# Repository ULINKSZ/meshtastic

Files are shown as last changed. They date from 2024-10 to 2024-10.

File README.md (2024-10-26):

# Meshtastic Product Development
Meshtastic devices can help explorers stay connected, share locations, send emergency distress signals, etc. in remote mountainous areas without mobile phone signals during outdoor activities such as hiking and mountaineering. In some small communities or remote villages, Meshtastic mesh networks can be built to meet local communication needs, such as community notifications and emergency warnings. In the event that natural disasters (such as earthquakes and floods) damage traditional communication infrastructure, Meshtastic devices can be quickly deployed to establish emergency communication networks to provide communication means for rescue workers and disaster victims.
=======
## Open source code link (https://github.com/meshtastic/meshtastic)
## The following are all the contents in this warehouse organized into separate directories. Each directory stores the corresponding information. When you need it, go to the specified directory to search. The name of each directory is shown below:
### Docs is the product hardware specification and hardware parameters
### Firmware is used to store the hex and bin files burned into the hardware
### Hardware/meshtastiv_V1.0 is the product schematic and PCB board. Please use Kicad software to open and view it. Kicad download address (https://www.kicad.org/)
### Instructions are product burning and usage methods and how to quickly locate. Please open the folder and click Meshtastic devices or How to quickly locate files to view them.
### Software/firmware-master is the product source code. Please download VSCode to open and view it. VsCode download address (https://code.visualstudio.com/)

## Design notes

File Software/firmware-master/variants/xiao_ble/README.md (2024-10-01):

#

<p align="center" style="font-size: 28px;">
    Xiao BLE/BLE Sense + Ebyte E22-900M30S
</p>

<p align="center" style="font-size: 20px;">
    A step-by-step guide for macOS and Linux
</p>

## Introduction

This guide will walk you through everything needed to get the Xiao BLE (or BLE Sense) running Meshtastic using an Ebyte E22-900M30S LoRa module. The combination of the E22 with an nRF52840 MCU is desirable because it allows for both very low idle (Rx) power draw <i>and</i> high transmit power. The Xiao BLE is a small but surprisingly well-appointed nRF52840 board, with enough GPIO for most Meshtastic applications and a built-in LiPo charger. The E22, on the other hand, is a famously inscrutable and mysterious beast. It is one of the more readily available LoRa modules capable of transmitting at 30 dBm, and includes an LNA to boost its Rx sensitivity a few dB beyond that of the SX1262. However, its documentation is relatively sparse overall, and seems to merely hint at (or completely omit) several key details regarding its functionality. Thus, much of what follows is a synthesis of my observations and inferences over the course of many hours of trial and error.

<h3>Acknowledgement and friendly disclaimer</h3>

Huge thanks to those in the community who have forged the way with the E22, without whose hard work none of this would have been possible! (thebentern, riddick, rainer_vie, beegee-tokyo, geeksville, caveman99, Der_Bear, PlumRugOfDoom, BigCorvus, and many others.)

<br>

Please take the conclusions here as a tentative work in progress, representing my current (and fairly limited) understanding of the E22 when paired with this particular MCU. It is my hope that this guide will be helpful to others who are interested in trying a DIY Meshtastic build, and also be subject to revision by folks with more experience and better test equipment.

### Obligatory liability disclaimer

This guide and all associated content is for informational purposes only. The information presented is intended for consumption only by persons having appropriate technical skill and judgement, to be used entirely at their own discretion and risk. The authors of this guide in no way provide any warranty, express or implied, toward the content herein, nor its correctness, safety, or suitability to any particular purpose. By following the instructions in this guide in part or in full, you assume all responsibility for all potential risks, including but not limited to fire, property damage, bodily injury, and death.

### Note

These instructions assume you are running macOS or Linux, but it should be relatively easy to translate each command for Windows. (In this case, in step 2 below, each line of `xiao_ble.sh` would also need to be converted to the equivalent Windows CLI command and run individually.)

## 1. Update Bootloader

The first thing you will need to do is update the Xiao BLE's bootloader. The stock bootloader is functionally very similar to the Adafruit nRF52 UF2 bootloader, but apparently not quite enough so to work with Meshtastic out of the box.

1. Connect the Xiao BLE to your computer via USB-C.

2. Install `adafruit-nrfutil` by following the instructions <a href="https://github.com/adafruit/Adafruit_nRF52_nrfutil">here</a>.

3. Open a terminal window and navigate to `firmware/variants/xiao_ble` (where `firmware` is the directory into which you have cloned the <a href="https://github.com/meshtastic/firmware">Meshtastic firmware repo</a>).

4. Run the following command, replacing `/dev/cu.usbmodem2101` with the serial port your Xiao BLE is connected to:

   ```bash
   adafruit-nrfutil --verbose dfu serial --package xiao_nrf52840_ble_bootloader-0.7.0-22-g277a0c8_s140_7.3.0.zip --port /dev/cu.usbmodem2101 -b 115200 --singlebank --touch 1200
   ```

5. If all goes well, the Xiao BLE's red LED should start to pulse slowly, and you should see a new USB storage device called `XIAO-BOOT` appear under `Locations` in Finder.

&nbsp;

## 2. PlatformIO Environment Preparation

Before building Meshtastic for the Xiao BLE + E22, it is necessary to pull in SoftDevice 7.3.0 and its associated linker script (nrf52840_s140_v7.ld) from Seeed Studio's Arduino core. The `xiao_ble.sh` script does this.

1. In your terminal window, run the following command:

   ```bash
   sudo ./xiao_ble.sh
   ```

&nbsp;

## 3. Build Meshtastic

At this point, you should be able to build the firmware successfully.

1. In VS Code, press `Command Shift P` to bring up the command palette.

2. Search for and run the `Developer: Reload Window` command.

3. Bring up the command palette again with `Command Shift P`. Search for and run the `PlatformIO: Pick Project Environment` command.

4. In the list of environments, select `env:xiao_ble`. PlatformIO may update itself for a minute or two, and should let you know once done.

5. Return to the command palette once again (`Command Shift P`). Search for and run the `PlatformIO: Build` command.

6. PlatformIO will build the project. After a few minutes you should see a green `SUCCESS` message.

&nbsp;

## 4. Wire the board

Connecting the E22 to the Xiao BLE is straightforward, but there are a few gotchas to be mindful of.

- <strong>On the Xiao BLE:</strong>

  - Pins D4 and D5 are currently mapped to `PIN_WIRE_SDA` and `PIN_WIRE_SCL`, respectively. If you are not using I²C and would like to free up pins D4 and D5 for use as GPIO, `PIN_WIRE_SDA` and `PIN_WIRE_SCL` can be reassigned to any two other unused pin numbers.

  - Pins D6 and D7 were originally mapped to the TX and RX pins for serial interface 1 (`PIN_SERIAL1_RX` and `PIN_SERIAL1_TX`) but are currently set to -1 in `variant.h`. If you need to expose a serial interface, you can restore these pins and move e.g. `SX126X_RXEN` to pin 4 or 5 (the opposite should work too).

- <strong>On the E22:</strong>

  - There are two options for the E22's `TXEN` pin:

    1. It can be connected to the MCU on the pin defined as `SX126X_TXEN` in `variant.h`. In this configuration, the MCU will control Tx/Rx switching "manually". As long as `SX126X_TXEN` and `SX126X_RXEN` are both defined in `variant.h` (and neither is set to `RADIOLIB_NC`), `SX126xInterface.cpp` will initialize the E22 correctly for this mode.

    2. Alternately, it can be connected to the E22's `DIO2` pin only, with neither `TXEN` nor `DIO2` being connected to the MCU. In this configuration, the E22 will control Tx/Rx switching automatically. In `variant.h`, as long as `SX126X_TXEN` is defined as `RADIOLIB_NC`, and `SX126X_RXEN` is defined and connected to the E22's `RXEN` pin, and `E22_TXEN_CONNECTED_TO_DIO2` is defined, `SX126xInterface.cpp` will initialize the E22 correctly for this mode. This configuration frees up a GPIO, and presents no drawbacks that I have found.

    - Note that any combination other than the two described above will likely result in unexpected behavior. In my testing, some of these other configurations appeared to "work" at first glance, but every one I tried had at least one of the following flaws: weak Tx power, extremely poor Rx sensitivity, or the E22 overheating because TXEN was never pulled low, causing its PA to stay on indefinitely.

    - Along the same lines, it is a good idea to check the E22's temperature frequently by lightly touching the shield. If you feel the shield getting hot (i.e. approaching uncomfortable to touch) near pins 1, 2, and 3, something is probably misconfigured; disconnect both the Xiao BLE and E22 from power and double check wiring and pin mapping.

  - Whether you opt to let the E22 control Rx and Tx or handle this manually, <strong>the E22's `RXEN` pin must always be connected to the MCU</strong> on the pin defined as `SX126X_RXEN` in `variant.h`.

<h3>Note</h3>

The default pin mapping in `variant.h` uses 'automatic Tx/Rx switching' mode. If you wire your board for manual Rx/Tx switching, make sure to update `variant.h` accordingly by commenting/uncommenting the necessary lines in the 'E22 Tx/Rx control options' section.

&nbsp;

---

&nbsp;

<h3>Example wiring for "E22 automatic Tx/Rx switching" mode:</h3>
&nbsp;

<strong>MCU -> E22 connections</strong>
| Xiao BLE pin | variant.h definition | E22 pin | Notes |
| :--- | :--- | :---| :--- |
| D0 | SX126X_CS | 19 (NSS) | |
| D1 | SX126X_DIO1 | 13 (DIO1) | |
| D2 | SX126X_BUSY | 14 (BUSY) | |
| D3 | SX126X_RESET | 15 (NRST) | |
| D7 | SX126X_RXEN | 6 (RXEN) | These pins must still be connected, and `SX126X_RXEN` defined in `variant.h`, otherwise Rx sensitivity will be poor. |
| D8 | PIN_SPI_SCK | 18 (SCK) | |
| D9 | PIN_SPI_MISO | 16 (MISO) | |
| D10 | PIN_SPI_MOSI | 17 (MOSI) | |

&nbsp;
&nbsp;

<strong>E22 -> E22 connections:</strong>
| E22 pin | E22 pin | Notes |
| :--- | :--- | :--- |
| TXEN | DIO2 | These must be physically connected for automatic Tx/Rx switching to work. |

<h3>Note</h3>

The schematic (`xiao-ble-e22-schematic.png`) in the `eagle-project` directory uses this wiring.

&nbsp;

---

&nbsp;

<h3>Example wiring for "Manual Tx/Rx switching" mode:</h3>

<strong>MCU -> E22 connections</strong>
| Xiao BLE pin | variant.h definition | E22 pin | Notes |
| :--- | :--- | :---| :--- |
| D0 | SX126X_CS | 19 (NSS) | |
| D1 | SX126X_DIO1 | 13 (DIO1) | |
| D2 | SX126X_BUSY | 14 (BUSY) | |
| D3 | SX126X_RESET | 15 (NRST) | |
| D6 | SX126X_TXEN | 7 (TXEN) | |
| D7 | SX126X_RXEN | 6 (RXEN) | |
| D8 | PIN_SPI_SCK | 18 (SCK) | |
| D9 | PIN_SPI_MISO | 16 (MISO) | |
| D10 | PIN_SPI_MOSI | 17 (MOSI) | |

<strong>E22 -> E22 connections:</strong> (none)

&nbsp;

## 5. Flash the firmware to the Xiao BLE

1. Double press the Xiao's `reset` button to put it in bootloader mode.
2. In a terminal window, navigate to the Meshtastic firmware repo's root directory, and from there to `.pio/build/xiao_ble`.
3. Convert the generated `.hex` file into a `.uf2` file:

   ```bash
   ../../../bin/uf2conv.py firmware.hex -c -o firmware.uf2 -f 0xADA52840
   ```

4. Copy the new `.uf2` file to the Xiao's mass storage volume:

   ```bash
   cp firmware.uf2 /Volumes/XIAO-BOOT
   ```

5. The Xiao's red LED will flash for several seconds as the firmware is copied.
6. Once the firmware is copied, to verify it is running, run the following command:

   ```bash
   meshtastic --noproto
   ```

7. Then, press the Xiao's `reset` button again. You should see a lot of debug output logged in the terminal window.

&nbsp;

## 6. Troubleshooting

- If after flashing Meshtastic, the Xiao is bootlooped, look at the serial output (you can see this by running `meshtastic --noproto` with the device connected to your computer via USB).

  - If you see that the SX1262 init result was -2, this likely indicates a wiring problem; double check your wiring and pin mapping in `variant.h`.

  - If you see an error mentioning tinyFS, this may mean you need to reformat the Xiao's storage:

    1. Double press the `reset` button to put the Xiao in bootloader mode.

    2. In a terminal window, navigate to the Meshtastic firmware repo's root directory, and from there to `variants/xiao_ble`.

    3. Run the following command: &nbsp;`cp xiao-ble-internal-format.uf2 /Volumes/XIAO-BOOT`

    4. The Xiao's red LED will flash briefly as the filesystem format firmware is copied.

    5. Run the following command: &nbsp;`meshtastic --noproto`

    6. In the output of the above command, you should see a message saying "Formatting...done".

    7. To flash Meshtastic again, repeat the steps in section 5 above.

  - If you don't see any specific error message, but the boot process is stuck or not proceeding as expected, this might also mean there is a conflict in `variant.h`. If you have made any changes to the pin mapping, ensure they do not result in a conflict. If all else fails, try reverting your changes and using the known-good configuration included here.

  - The above might also mean something is wired incorrectly. Try reverting to one of the known-good example wirings in section 4.

- If the E22 gets hot to the touch:
  - The power amplifier is likely running continually. Disconnect it and the Xiao from power immediately, and double check wiring and pin mapping. In my experimentation this occurred in cases where TXEN was inadvertenly high (usually due to a pin mapping conflict).

&nbsp;

## 7. Notes

- There are several anecdotal recommendations regarding the Tx power the E22's internal SX1262 should be set to in order to achieve the advertised output of 30 dBm, ranging from 4 (per <a href="https://github.com/jgromes/RadioLib/wiki/High-power-Radio-Modules-Guide">this article</a> in the RadioLib github repo) to 22 (per <a href="https://discord.com/channels/867578229534359593/871539930852130866/976472577545490482">this conversation</a> from the Meshtastic Discord). When paired with the Xiao BLE in the configurations described above, I observed that the output is at its maximum when Tx power is set to 22.

- To achieve its full output, the E22 should have a bypass capacitor from its 5V supply to ground. 100 µF works well.

- The E22 will happily run on voltages lower than 5V, but the full output power will not be realized. For example, with a fully charged LiPo at 4.2V, Tx power appears to max out around 26-27 dBm.

&nbsp;

## 8. Testing Methodology

During what became a fairly long trial-and-error process, I did a lot of careful testing of Tx power and Rx sensitivity. My methodology in these tests was as follows:

- All tests were conducted between two nodes:

  1. The Xiao BLE + E22 coupled with an <a href="https://www.digikey.com/en/products/detail/abracon-llc/ARRKP4065-S915A/8593263">Abracon ARRKP4065-S915A</a> ceramic patch antenna

  2. A RAK 5005/4631 coupled with a <a href="https://www.streakwave.com/laird-technologies-ma9-5n-55dbi-900mhz-mobile-omni-select-mount">Laird MA9-5N</a> antenna via a 4" U.FL to Type N pigtail.

  - No other nodes were powered up onsite or nearby.

    <br>

- Each node and its antenna was kept in exactly the same position and orientation throughout testing.

- Other environmental factors (e.g. the location and resting position of my body in the room while testing) were controlled as carefully as possible.

- Each test comprised at least five (and often ten) runs, after which the results were averaged.

- All testing was done by sending single-character messages between nodes and observing the received RSSI reported in the message acknowledgement. Messages were sent one by one, waiting for each to be acknowledged or time out before sending the next.

- The E22's Tx power was observed by sending messages from the RAK to the Xiao BLE + E22 and recording the received RSSI.

- The opposite was done to observe the E22's Rx sensitivity: messages were sent from the Xiao BLE + E22 to the RAK, and the received RSSI was recorded.

While this cannot match the level of accuracy achievable with actual test equipment in a lab setting, it was nonetheless sufficient to demonstrate the (sometimes very large) differences in Tx power and Rx sensitivity between various configurations.

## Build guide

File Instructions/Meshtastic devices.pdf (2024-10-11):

# Meshtastic devices

# Project Overview

1. Meshtastic devices can help explorers stay connected in remote

mountainous areas where there is no mobile phone signal, share location, send

emergency distress signals, etc. 2. In some small communities or remote villages, Meshtastic mesh networks

can be built to meet local communication needs, such as notification and

emergency warning in the community. 3. In the event of damage to traditional communication infrastructure caused

by natural disasters (such as earthquakes, floods, etc.), Meshtastic equipment

can be quickly deployed to establish an emergency communication network to

provide a means of communication for rescuers and affected people. Equipment specifications

1. Hardware specifications
1. Hardware device type: wireless communication equipment, GPS positioning

sensor

2. Dimensions and weight: length 4.8cm, width 1.3cm, height 0.9cm
3. Power requirements: 180mAh battery
4. Processor and memory: 32-bit ARM Cortex-M4F processor, 256KB RAM

(random access memory) and 1MB Flash (flash memory). 5. Communication interface: LoRa wireless communication

6. Sensor characteristics: diversified data collection, perception of location

information, low power operation, high sensitivity and accuracy, good

compatibility. 7. Actuator characteristics: remote control capability, fast response, reliability

# and stability. User Interface Specifications (Applications)

1. Interface layout
1. Function menu: for adding devices to connect devices
2. Contact management: Each contact displays information such as name, node

address, etc., which is convenient for users to quickly select contacts to send

messages

3. Map view: The Mesh app interface provides a map view option, which can

display the geographical location of each node on the map

2. Interactive functions
1. Text messages: Users can send and receive text messages to facilitate

simple text communication, such as communicating routes, plans and other

information between teammates during outdoor adventures. 2. Custom message format: Users can define the message format according

to their own needs, which enhances the flexibility and applicability of the

function and meets the special requirements for message content and format

in different scenarios.

3. The device is integrated with a GPS module, which can transmit the

location information of the device in real time. This is useful for outdoor

activities, emergency rescue, and other scenarios, where team members can

quickly understand each other's location for gathering, rescue, or collaborative

# action. Use the specification configuration to burn in

1. Download Visual Studio Code and download Platformio as an extension
2. Download the meshtastic-master archive in GitHub and decompress it

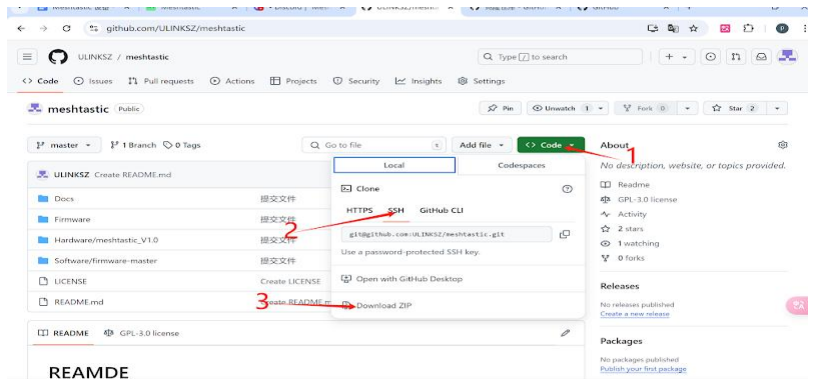
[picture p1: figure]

https://github.com/ULINKSZ/meshtastic

3. Open the firmware-master folder with Visual Studio Code
4. Open

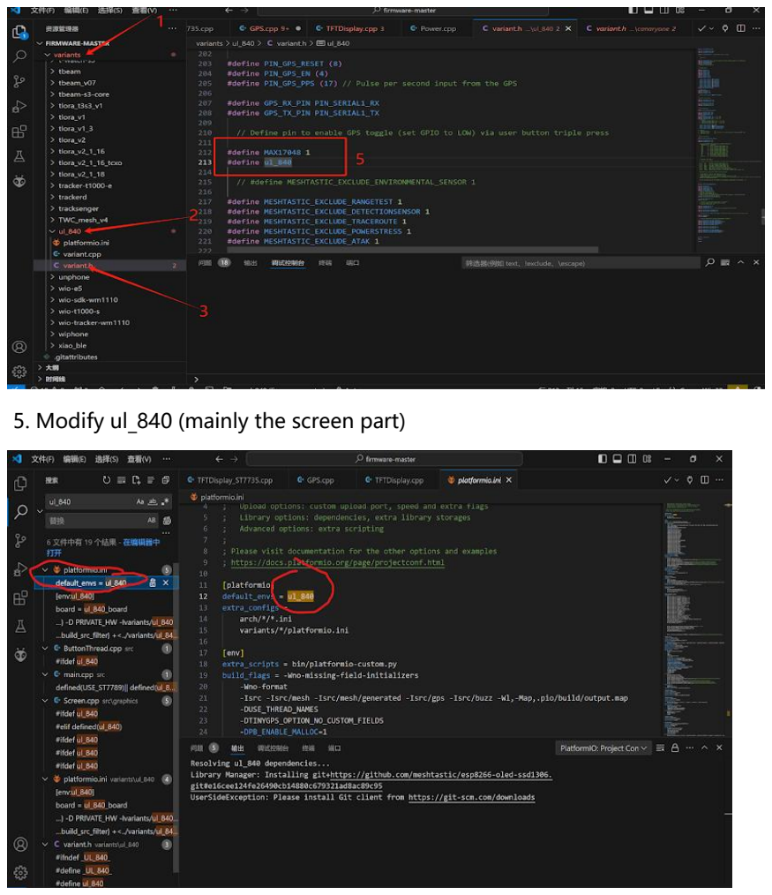
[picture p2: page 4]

5. Modify ul_840 (mainly the screen part)

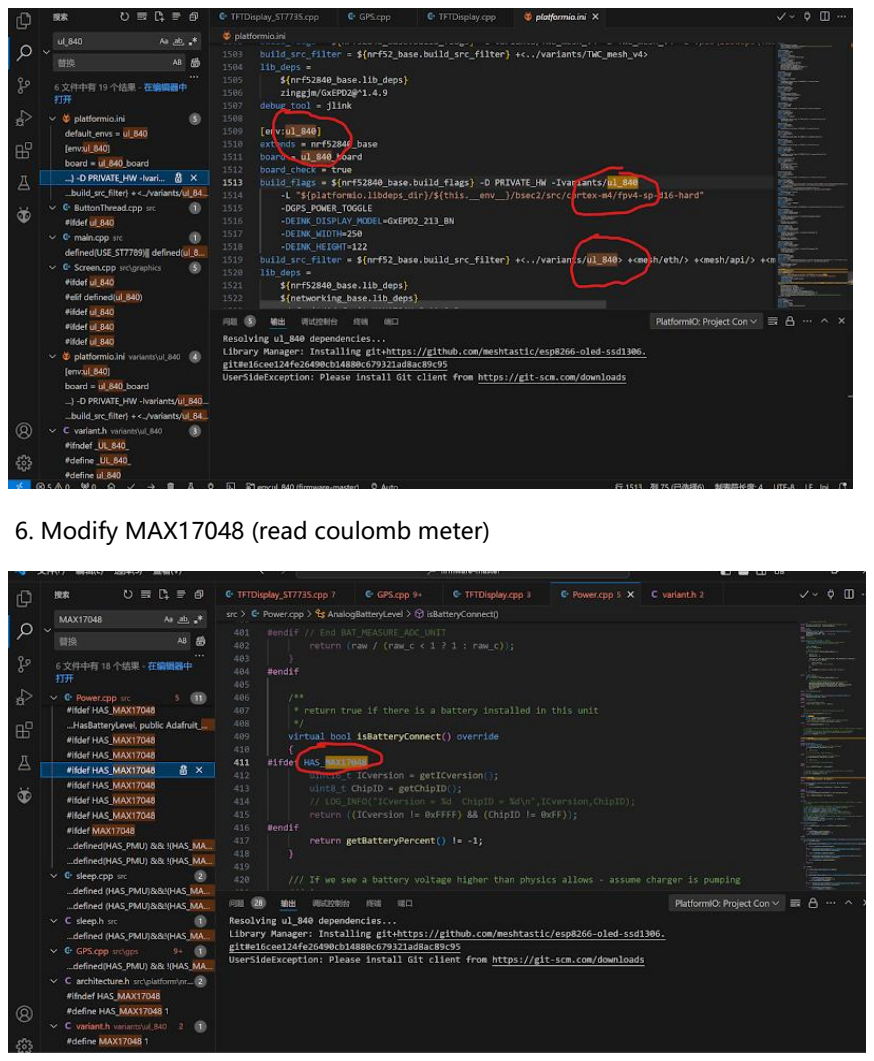
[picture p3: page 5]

6. Modify MAX17048 (read coulomb meter)

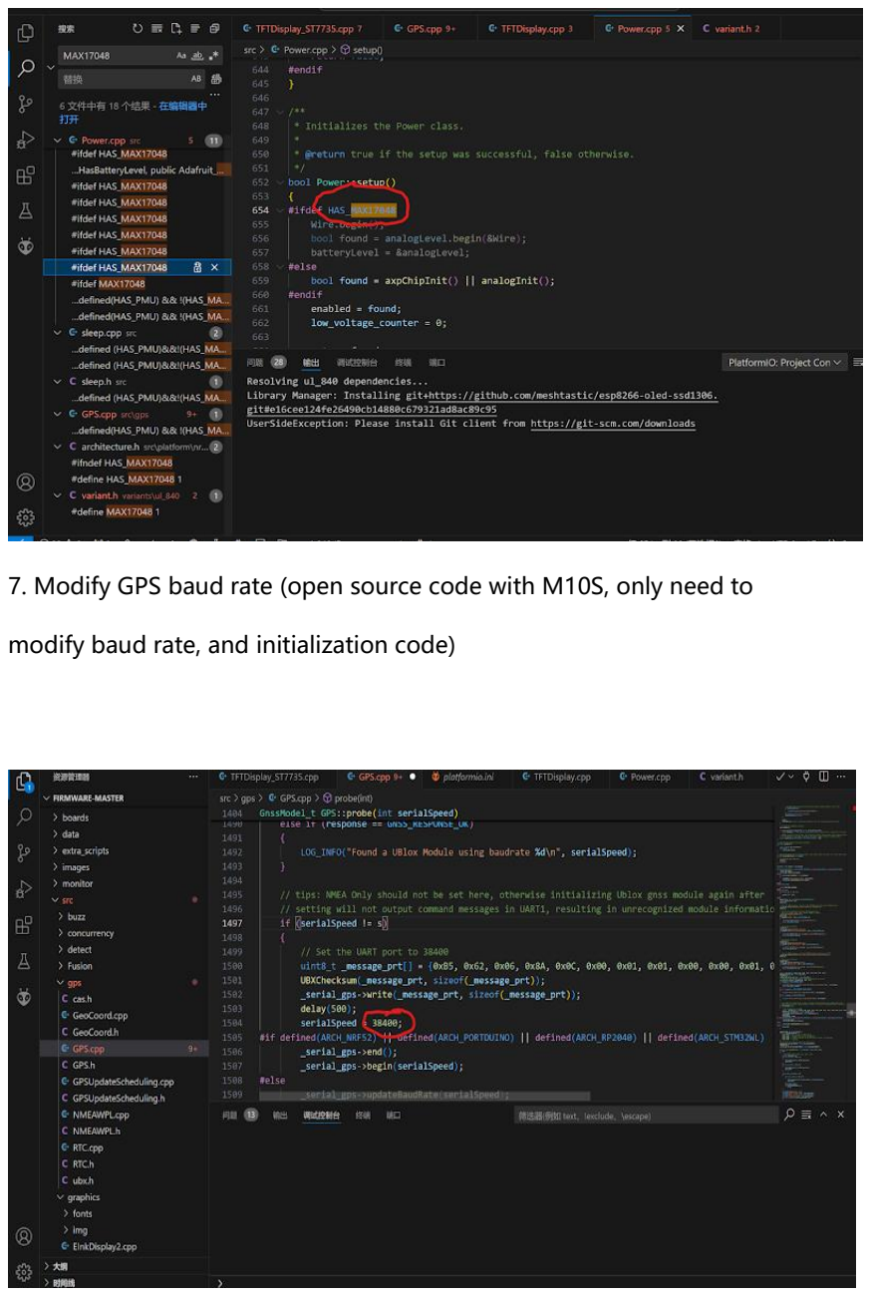
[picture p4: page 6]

7. Modify GPS baud rate (open source code with M10S, only need to

modify baud rate, and initialization code)

8. Configure the serial port

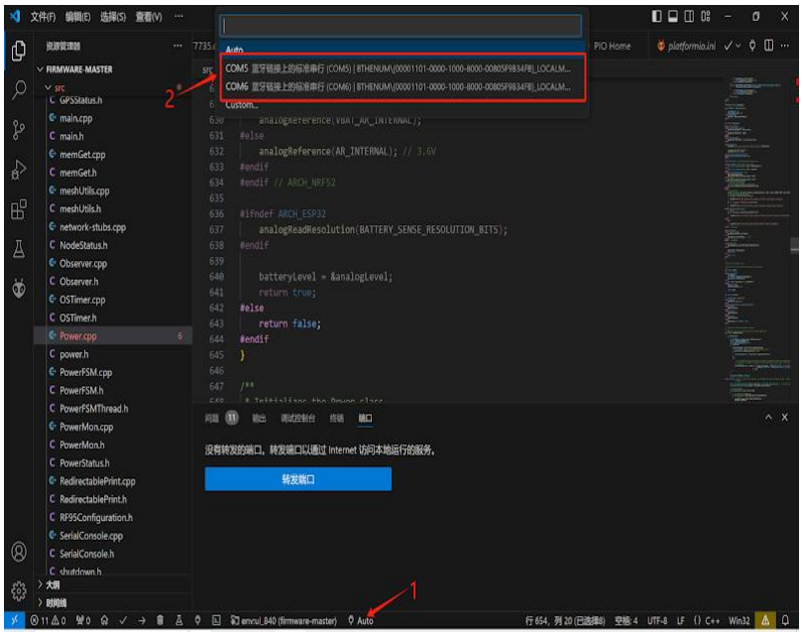
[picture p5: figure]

9. Click √ to compile 1 compilation successfully, compile correctly, click

the arrow to burn in 2 burn successfully.

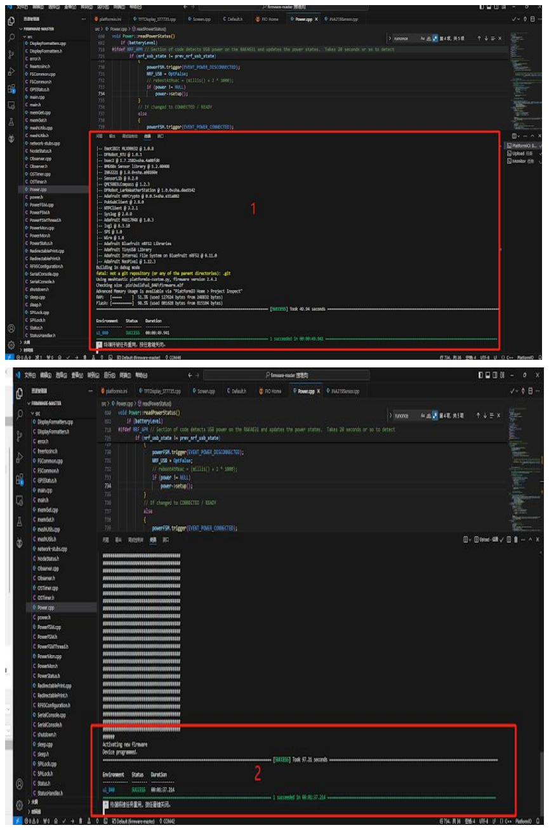
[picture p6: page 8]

# button to use

1. Power off to the left and power on to the right

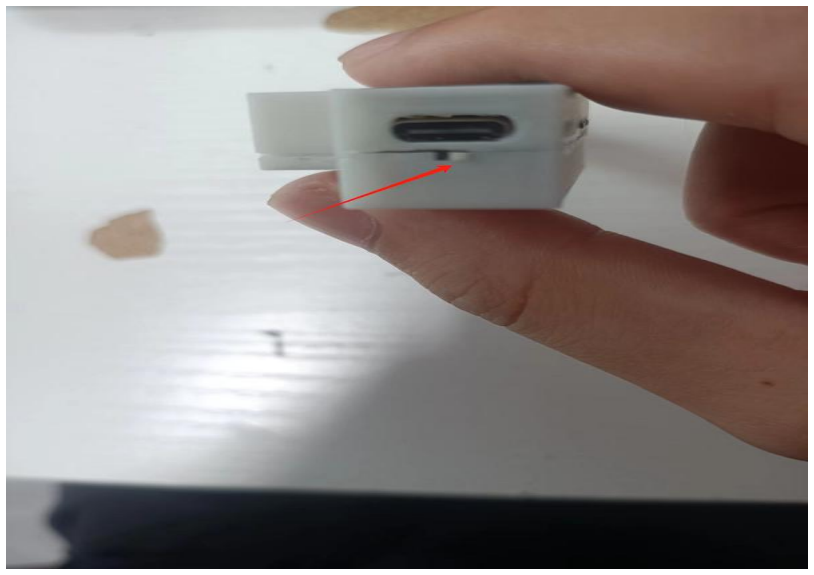
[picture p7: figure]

2. Stand-alone 1 switches the upper and lower navigation bars, stand-alone 2

enters the navigation bar, and stand-alone 3 restarts

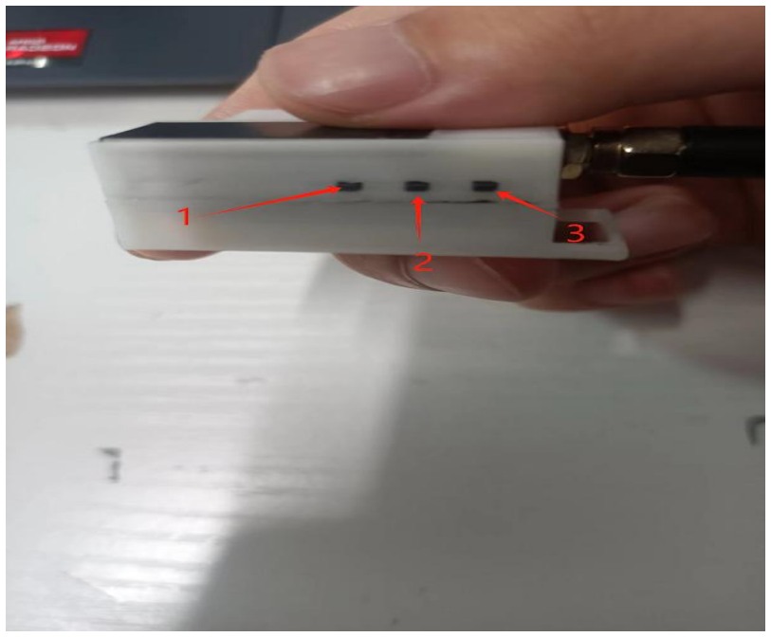
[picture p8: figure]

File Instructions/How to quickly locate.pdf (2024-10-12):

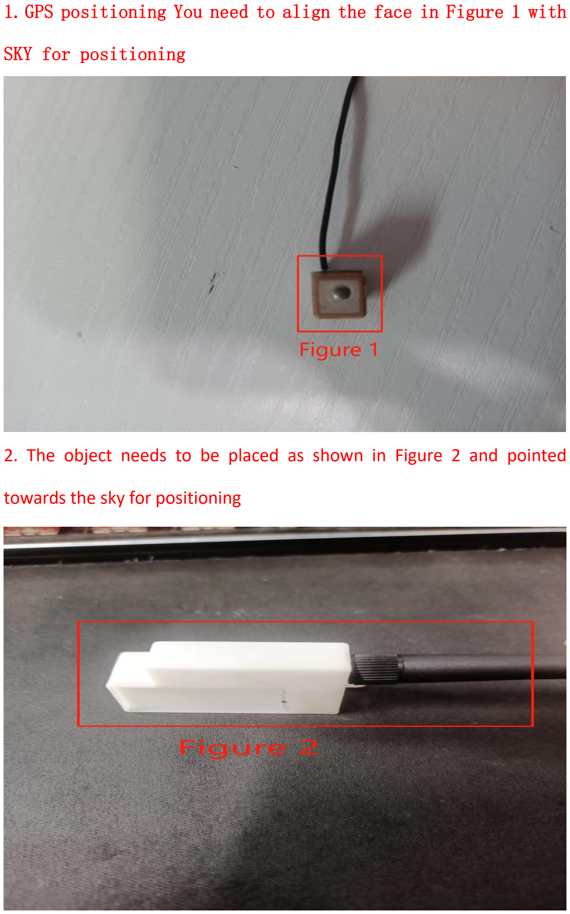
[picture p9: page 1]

1.GPS positioning You need to align the face in Figure 1 with

SKY for positioning

2. The object needs to be placed as shown in Figure 2 and pointed towards the sky for positioning

3.GPS storage location

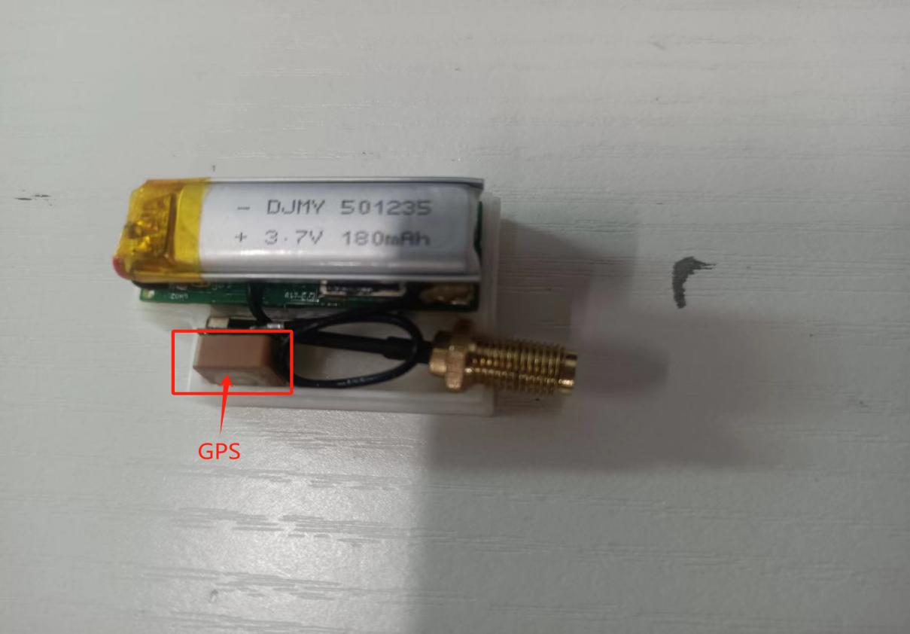
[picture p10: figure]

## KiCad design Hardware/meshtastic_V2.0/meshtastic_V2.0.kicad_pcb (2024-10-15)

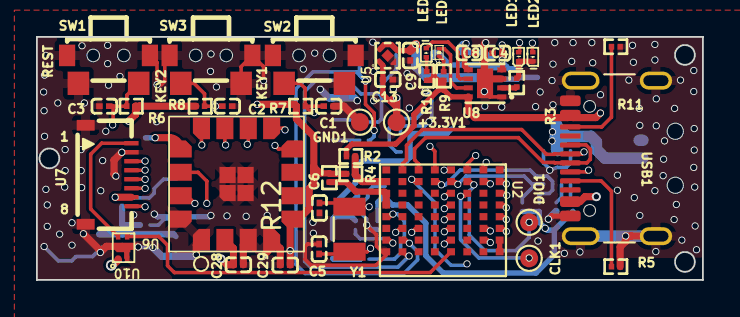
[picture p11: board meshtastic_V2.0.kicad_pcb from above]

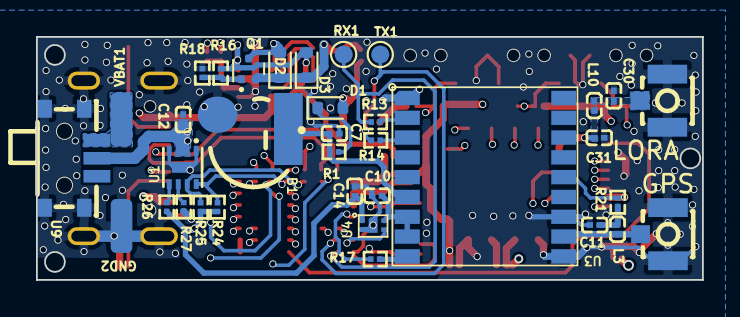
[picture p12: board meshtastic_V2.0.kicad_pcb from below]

Board: 4 copper layers, 37.0 x 13.5 mm, 76 parts (35 on the bottom side), 61 nets.

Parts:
+3.3V1: TEXT; TestPoint_Pad_D1.0mm
B1: XH414H-IV01E 3.3V0.08F; CAP-SMD_2P-L4.8-W4.8-TR
C1, C2, C3, C10, C28, C29: 100nF; C0201
C4, C7, C8, C12: 1uF; C0201
C5, C6: 12pF; C0201
C9, C13, C14: 105; C0201
C11: 10nF; C0201
C30, C31: 3.3pF; C0201
CLK1: TEXT; TestPoint_Pad_D1.0mm
D1, D2, D3: LRB521S-40T1G; D_SOD-523
DIO1: TEXT; TestPoint_Pad_D1.0mm
GND1: TEXT; TestPoint_Pad_D1.0mm
GND2: GND; 1P_TEST
L3: 2.66R VHF060303H68NJT; L0201
L10: 9.1nH; L0201
LED1: XL-0201UGC; LED-SMD_L0.7-W0.4-RD_GREEN
LED2: XL-0201UBC; LED-SMD_L0.7-W0.4-RD_BLUE
LED5: XL-0201SURC; LED-SMD_L0.65-W0.35-P0.41_XL-0201SURC
LED6: XL-0201UGC/NC; LED-SMD_L0.7-W0.4-RD_GREEN
Q1: CJ3139K; SOT-723
R1: 3.3K; R0201
R2, R12: 0R; R0201
R3: 9K; R0201
R4: 0R/NC; R0201
R5, R11: 499R; R0201
R6, R7, R8, R18, R27: 10K; R0201
R9: 1K; R0201
R10: 1K/NC; R0201
R13, R14, R17: 33; R0201
R16: 100R; R0201
R21: 10R; R0201
R24, R25, R26: 4.7K; R0201
RF1, RF2: IPEX(1代); IPEX
RX1: TEXT; TestPoint_Pad_D1.0mm
SW1, SW2, SW3: TS24CA; SW-SMD_TS24CA
TX1: TEXT; TestPoint_Pad_D1.0mm
U1: MAX17048G+T10; DFN-8-2x2-P0.5
U2: UL840; UL-840
U3: MAX-M10S-00B-01; MAX-M10S
U4, U10: DIO7330B; DFN-4
U5: RT9073A-33GQZ
U6: HJ-68LR(12); UL62
U7: AFC42-S08FMA-1H; FFC-SMD_8P-P0.50_AFC42-S08FMA-1H
U8: LGS4056HDA; DFN-8_L2.0-W2.0-P0.50-BL-EP
U9: MINI_MSK12CO2; SW-SMD_MSK12CO2
USB1: type-16pin; USB_C_Receptacle_GCT_USB4105-xx-A_16P_TopMnt_Horizontal
VBAT1: BAT; 1P_TEST
Y1: 32.768kHz; Crystal_SMD_3215-2Pin_3.2x1.5mm

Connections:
+3.3V: +3.3V1.1, C13.1, C14.2, C28.1, C29.2, D1.2 (A), R4.2, R6.2, R7.2, R8.2, R12.2, R24.1, R25.1, R26.1, U4.1 (VIN), U5.1 (VOUT), U6.2 (VCC), U6.5 (VCC), U7.7 (VDD), U10.1 (VIN)
+BATT: C8.1, C12.1, D2.2 (A), Q1.3 (D), U1.2 (CELL), U1.3 (VDD), U8.5 (BAT), U9.2
/BACKUP: B1.1, C7.1, R1.2, U3.6 (V_BCKP)
/D+: U2.F1 (D+), USB1.A6 (DP1), USB1.B6 (DP2)
/D-: U2.G1 (D-), USB1.A7 (DN1), USB1.B7 (DN2)
/GPS-EN: U2.H7 (P0.04), U4.3 (EN)
/Max_RESET: R17.2, U2.H5 (P0.08)
/RADIO_BUSY: U2.C1 (P0.25), U6.9 (BUSY)
/RADIO_DIO_1: U2.D1 (P0.19), U6.8 (DIO1)
/RADIO_RESET: U2.B1 (P0.22), U6.10 (RST)
/RESET: C3.1, R6.1, SW1.4, U2.E1 (P0.18/RESET)
/RF_ANT: C31.1, L10.1, U6.13 (ANT)
/RX: R13.2, RX1.1, U2.G8 (P0.06)
/SCL: R25.2, U1.7 (SCL), U2.E2 (P0.15)
/SDA: R24.2, U1.8 (SDA), U2.D2 (P1.00)
/SPI_MISO: U2.B2 (P1.04), U6.11 (MISO)
/SPI_MOSI: U2.A4 (P0.20), U6.14 (MOSI)
/SPI_NSS: U2.A3 (P0.21), U6.15 (NSS)
/SPI_SCLK: U2.A2 (P1.01), U6.12 (SCK)
/SWCLK: CLK1.1, U2.C3 (SWCLK)
/SWDI0: DIO1.1, U2.C2 (SWDIO)
/TX: R14.2, TX1.1, U2.G7 (P0.26)
GND: B1.2, C1.1, C2.1, C3.2, C4.2, C5.2, C6.2, C7.2, C8.2, C9.2, C10.2, C11.2, C12.2, C13.2, C14.1, C28.2, C29.1, C30.2, C31.2, GND1.1, GND2.1, LED1.1 (K), LED2.1 (K), R3.1, R5.1, R11.1, R18.1, R27.2, RF1.2 (GND), RF1.3 (GND), RF2.2 (GND), RF2.3 (GND), SW1.1, SW1.2, SW1.3, SW2.1, SW2.2, SW2.4, SW3.1, SW3.2, SW3.4, U1.1 (CTG), U1.4 (GND), U1.9 (EP), U2.A1 (GND), U2.H8 (GND), U3.1 (GND), U3.10 (GND), U3.12 (GND), U4.2 (GND), U4.5 (GND), U5.2 (GND), U5.5 (GND), U6.1 (GND), U6.3 (GND), U6.4 (GND), U6.16 (GND), U6.17 (GND), U7.2 (GND), U7.9 (GND), U7.10 (GND), U8.1 (TEMP), U8.3 (GND), U8.9 (PAD), U9.4, U9.5, U10.2 (GND), U10.5 (GND), USB1.A1 (GND), USB1.A12 (GND), USB1.B1 (GND), USB1.B12 (GND), USB1.S1 (SHELL)
KEY1: C1.2, R7.1, SW2.3, U2.A5 (P0.17)
KEY2: C2.2, R8.1, SW3.3, U2.A6 (P0.14)
LCD_CS: U2.D7 (P1.13), U7.8 (CS)
LCD_DC: U2.D4 (P1.03), U7.4 (D/C)
LCD_REST: U2.D3 (P1.02), U7.3 (RESET)
LCD_SCL: U2.D6 (P1.10), U7.6 (SCL)
LCD_SDA: U2.D5 (P0.23), U7.5 (SDA)
LEDA: U7.1 (LEDA), U10.4 (VOUT)
LEDK: U2.D8 (P0.31), U10.3 (EN)
LED_GREEM: LED2.2 (A), U2.B7 (P1.06)
LED_RED: LED1.2 (A), U2.B6 (P0.24)
unnamed: C11.1, L3.1, R21.1
unnamed: D1.1 (K), R1.1
unnamed: LED5.1 (A), R9.1
unnamed: LED5.2 (K), U8.7 (CHRG)
unnamed: LED6.2 (A), R10.1
unnamed: LED6.1 (K), U8.6 (DONE)
unnamed: Q1.1 (G), R16.2, R18.2
unnamed: R12.1, U2.H3 (VDD), U2.H4 (VDD)
unnamed: L3.2, RF1.1 (SIG), U3.11 (RF_IN)
unnamed: C30.1, L10.2, RF2.1 (SIG)
unnamed: R26.2, U1.5 (ALRT#)
unnamed: R27.1, U1.6 (QSTRT)
unnamed: U2.A7 (ANT), U2.A8 (BOARD_ANT)
unnamed: C6.1, U2.F6 (P0.00), Y1.2
unnamed: C5.1, U2.G6 (P0.01), Y1.1
unnamed: R2.1, R4.1, U2.H2 (VDDH)
unnamed: R17.1, U3.9 (RESET_N)
unnamed: R14.1, U3.3 (RXD)
unnamed: R13.1, U3.2 (TXD)
unnamed: C10.1, U3.7 (V_IO), U3.8 (VCC), U4.4 (VOUT)
unnamed: R21.2, U3.14 (VCC_RF)
unnamed: R3.2, U8.2 (PROG)
unnamed: R5.2, USB1.A5 (CC1)
unnamed: R11.2, USB1.B5 (CC2)
VAA: U9.1, VBAT1.1
VBUS: C4.1, D3.2 (A), R2.2, R9.2, R10.2, R16.1, U2.F2 (VBUS), U8.4 (VCC), U8.8 (CE), USB1.A4 (VBUS), USB1.A9 (VBUS), USB1.B4 (VBUS), USB1.B9 (VBUS)
VCC: C9.1, D2.1 (K), D3.1 (K), Q1.2 (S), U5.3 (EN), U5.4 (VIN)

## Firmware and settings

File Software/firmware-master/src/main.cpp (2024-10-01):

#include "configuration.h"
#if !MESHTASTIC_EXCLUDE_GPS
#include "GPS.h"
#endif
#include "MeshRadio.h"
#include "MeshService.h"
#include "NodeDB.h"
#include "PowerFSM.h"
#include "PowerMon.h"
#include "ReliableRouter.h"
#include "airtime.h"
#include "buzz.h"

#include "error.h"
#include "power.h"
// #include "debug.h"
#include "FSCommon.h"
#include "RTC.h"
#include "SPILock.h"
#include "concurrency/OSThread.h"
#include "concurrency/Periodic.h"
#include "detect/ScanI2C.h"

#if !MESHTASTIC_EXCLUDE_I2C
#include "detect/ScanI2CTwoWire.h"
#include <Wire.h>
#endif
#include "detect/axpDebug.h"
#include "detect/einkScan.h"
#include "graphics/RAKled.h"
#include "graphics/Screen.h"
#include "main.h"
#include "mesh/generated/meshtastic/config.pb.h"
#include "modules/Modules.h"
#include "shutdown.h"
#include "sleep.h"
#include "target_specific.h"
#include <memory>
#include <utility>
// #include <driver/rtc_io.h>

#ifdef ARCH_ESP32
#if !MESHTASTIC_EXCLUDE_WEBSERVER
#include "mesh/http/WebServer.h"
#endif
#if !MESHTASTIC_EXCLUDE_BLUETOOTH
#include "nimble/NimbleBluetooth.h"
NimbleBluetooth *nimbleBluetooth = nullptr;
#endif
#endif

#ifdef ARCH_NRF52
#include "NRF52Bluetooth.h"
NRF52Bluetooth *nrf52Bluetooth = nullptr;
#endif

#if HAS_WIFI
#include "mesh/api/WiFiServerAPI.h"
#include "mesh/wifi/WiFiAPClient.h"
#endif

#if HAS_ETHERNET
#include "mesh/api/ethServerAPI.h"
#include "mesh/eth/ethClient.h"
#endif

#if !MESHTASTIC_EXCLUDE_MQTT
#include "mqtt/MQTT.h"
#endif

#include "LLCC68Interface.h"
#include "LR1110Interface.h"
#include "LR1120Interface.h"
#include "RF95Interface.h"
#include "SX1262Interface.h"
#include "SX1268Interface.h"
#include "SX1280Interface.h"
#include "detect/LoRaRadioType.h"

#ifdef ARCH_STM32WL
#include "STM32WLE5JCInterface.h"
#endif

#if !HAS_RADIO && defined(ARCH_PORTDUINO)
#include "platform/portduino/SimRadio.h"
#endif

#ifdef ARCH_PORTDUINO
#include "linux/LinuxHardwareI2C.h"
#include "mesh/raspihttp/PiWebServer.h"
#include "platform/portduino/PortduinoGlue.h"
#include <fstream>
#include <iostream>
#include <string>
#endif

#if HAS_BUTTON || defined(ARCH_PORTDUINO)
#include "ButtonThread.h"
#endif

#include "AmbientLightingThread.h"
#include "PowerFSMThread.h"

#if !defined(ARCH_PORTDUINO) && !defined(ARCH_STM32WL) && !MESHTASTIC_EXCLUDE_ENVIRONMENTAL_SENSOR
#include "AccelerometerThread.h"
AccelerometerThread *accelerometerThread = nullptr;
#endif

#ifdef HAS_I2S
#include "AudioThread.h"
AudioThread *audioThread = nullptr;
#endif

using namespace concurrency;

// We always create a screen object, but we only init it if we find the hardware
graphics::Screen *screen = nullptr;

// Global power status
meshtastic::PowerStatus *powerStatus = new meshtastic::PowerStatus();

// Global GPS status
meshtastic::GPSStatus *gpsStatus = new meshtastic::GPSStatus();

// Global Node status
meshtastic::NodeStatus *nodeStatus = new meshtastic::NodeStatus();

// Scan for I2C Devices

/// The I2C address of our display (if found)
ScanI2C::DeviceAddress screen_found = ScanI2C::ADDRESS_NONE;

// The I2C address of the cardkb or RAK14004 (if found)
ScanI2C::DeviceAddress cardkb_found = ScanI2C::ADDRESS_NONE;
// 0x02 for RAK14004, 0x00 for cardkb, 0x10 for T-Deck
uint8_t kb_model;

// The I2C address of the RTC Module (if found)
ScanI2C::DeviceAddress rtc_found = ScanI2C::ADDRESS_NONE;
// The I2C address of the Accelerometer (if found)
ScanI2C::DeviceAddress accelerometer_found = ScanI2C::ADDRESS_NONE;
// The I2C address of the RGB LED (if found)
ScanI2C::FoundDevice rgb_found = ScanI2C::FoundDevice(ScanI2C::DeviceType::NONE, ScanI2C::ADDRESS_NONE);

#if !defined(ARCH_PORTDUINO) && !defined(ARCH_STM32WL)
ATECCX08A atecc;
#endif

#ifdef T_WATCH_S3
Adafruit_DRV2605 drv;
#endif

// Global LoRa radio type
LoRaRadioType radioType = NO_RADIO;

bool isVibrating = false;

bool eink_found = true;

uint32_t serialSinceMsec;
bool pauseBluetoothLogging = false;

bool pmu_found;

#if !MESHTASTIC_EXCLUDE_I2C
// Array map of sensor types with i2c address and wire as we'll find in the i2c scan
std::pair<uint8_t, TwoWire *> nodeTelemetrySensorsMap[_meshtastic_TelemetrySensorType_MAX + 1] = {};
#endif

Router *router = NULL; // Users of router don't care what sort of subclass implements that API

const char *getDeviceName()
{
    uint8_t dmac[6];

    getMacAddr(dmac);

    // Meshtastic_ab3c or Shortname_abcd
    static char name[20];
    snprintf(name, sizeof(name), "%02x%02x", dmac[4], dmac[5]);
    // if the shortname exists and is NOT the new default of ab3c, use it for BLE name.
    if (strcmp(owner.short_name, name) != 0) {
        snprintf(name, sizeof(name), "%s_%02x%02x", owner.short_name, dmac[4], dmac[5]);
    } else {
        snprintf(name, sizeof(name), "Meshtastic_%02x%02x", dmac[4], dmac[5]);
    }
    return name;
}

static int32_t ledBlinker()
{
    // Still set up the blinking (heartbeat) interval but skip code path below, so LED will blink if
    // config.device.led_heartbeat_disabled is changed
    if (config.device.led_heartbeat_disabled)
        return 1000;

    static bool ledOn;
    ledOn ^= 1;

    setLed(ledOn);

    // have a very sparse duty cycle of LED being on, unless charging, then blink 0.5Hz square wave rate to indicate that
    return powerStatus->getIsCharging() ? 1000 : (ledOn ? 1 : 1000);
}

uint32_t timeLastPowered = 0;

static Periodic *ledPeriodic;
static OSThread *powerFSMthread;
static OSThread *ambientLightingThread;
SPISettings spiSettings(4000000, MSBFIRST, SPI_MODE0);

RadioInterface *rIf = NULL;

/**
 * Some platforms (nrf52) might provide an alterate version that suppresses calling delay from sleep.
 */
__attribute__((weak, noinline)) bool loopCanSleep()
{
    return true;
}

/**
 * Print info as a structured log message (for automated log processing)
 */
void printInfo()
{
    LOG_INFO("S:B:%d,%s\n", HW_VENDOR, optstr(APP_VERSION));
}

void setup()
{
    concurrency::hasBeenSetup = true;
    meshtastic_Config_DisplayConfig_OledType screen_model =
        meshtastic_Config_DisplayConfig_OledType::meshtastic_Config_DisplayConfig_OledType_OLED_AUTO;
    OLEDDISPLAY_GEOMETRY screen_geometry = GEOMETRY_128_64;

#ifdef USE_SEGGER
    auto mode = false ? SEGGER_RTT_MODE_BLOCK_IF_FIFO_FULL : SEGGER_RTT_MODE_NO_BLOCK_TRIM;
#ifdef NRF52840_XXAA
    auto buflen = 4096; // this board has a fair amount of ram
#else
    auto buflen = 256; // this board has a fair amount of ram
#endif
    SEGGER_RTT_ConfigUpBuffer(SEGGER_STDOUT_CH, NULL, NULL, buflen, mode);
#endif

#ifdef DEBUG_PORT
    consoleInit(); // Set serial baud rate and init our mesh console
#endif
    powerMonInit();

    serialSinceMsec = millis();

    LOG_INFO("\n\n//\\ E S H T /\\ S T / C\n\n");

    initDeepSleep();

    // power on peripherals
#if defined(PIN_POWER_EN)
    pinMode(PIN_POWER_EN, OUTPUT);
    digitalWrite(PIN_POWER_EN, HIGH);
    // digitalWrite(PIN_POWER_EN1, INPUT);
#endif

#if defined(LORA_TCXO_GPIO)
    pinMode(LORA_TCXO_GPIO, OUTPUT);
    digitalWrite(LORA_TCXO_GPIO, HIGH);
#endif

#if defined(VEXT_ENABLE_V03)
    pinMode(VEXT_ENABLE_V03, OUTPUT);
    pinMode(ST7735_BL_V03, OUTPUT);
    digitalWrite(VEXT_ENABLE_V03, 0); // turn on the display power and antenna boost
    digitalWrite(ST7735_BL_V03, 1);   // display backligth on
    LOG_DEBUG("HELTEC Detect Tracker V1.0\n");
#elif defined(VEXT_ENABLE_V05)
    pinMode(VEXT_ENABLE_V05, OUTPUT);
    pinMode(ST7735_BL_V05, OUTPUT);
    digitalWrite(VEXT_ENABLE_V05, 1); // turn on the lora antenna boost
    digitalWrite(ST7735_BL_V05, 1);   // turn on display backligth
    LOG_DEBUG("HELTEC Detect Tracker V1.1\n");
#elif defined(VEXT_ENABLE) && defined(VEXT_ON_VALUE)
    pinMode(VEXT_ENABLE, OUTPUT);
    digitalWrite(VEXT_ENABLE, VEXT_ON_VALUE); // turn on the display power
#elif defined(VEXT_ENABLE)
    pinMode(VEXT_ENABLE, OUTPUT);
    digitalWrite(VEXT_ENABLE, 0); // turn on the display power
#endif

#if defined(VGNSS_CTRL_V03)
    pinMode(VGNSS_CTRL_V03, OUTPUT);
    digitalWrite(VGNSS_CTRL_V03, LOW);
#endif

#if defined(VTFT_CTRL_V03)
    pinMode(VTFT_CTRL_V03, OUTPUT);
    digitalWrite(VTFT_CTRL_V03, LOW);
#endif

#if defined(VGNSS_CTRL)
    pinMode(VGNSS_CTRL, OUTPUT);
    digitalWrite(VGNSS_CTRL, LOW);
#endif

#if defined(VTFT_CTRL)
    pinMode(VTFT_CTRL, OUTPUT);
    digitalWrite(VTFT_CTRL, LOW);
#endif

#ifdef RESET_OLED
    pinMode(RESET_OLED, OUTPUT);
    digitalWrite(RESET_OLED, 1);
#endif

#ifdef PERIPHERAL_WARMUP_MS
    // Some peripherals may require additional time to stabilize after power is connected
    // e.g. I2C on Heltec Vision Master
    LOG_INFO("Waiting for peripherals to stabilize\n");
    delay(PERIPHERAL_WARMUP_MS);
#endif

#ifdef BUTTON_PIN
#ifdef ARCH_ESP32

    // If the button is connected to GPIO 12, don't enable the ability to use
    // meshtasticAdmin on the device.
    pinMode(config.device.button_gpio ? config.device.button_gpio : BUTTON_PIN, INPUT);

#ifdef BUTTON_NEED_PULLUP
    gpio_pullup_en((gpio_num_t)(config.device.button_gpio ? config.device.button_gpio : BUTTON_PIN));
    delay(10);
#endif

#endif
#endif

    OSThread::setup();

    ledPeriodic = new Periodic("Blink", ledBlinker);

    fsInit();

#if defined(_SEEED_XIAO_NRF52840_SENSE_H_)

    pinMode(CHARGE_LED, INPUT); // sets to detect if charge LED is on or off to see if USB is plugged in

    pinMode(HICHG, OUTPUT);
    digitalWrite(HICHG, LOW); // 100 mA charging current if set to LOW and 50mA (actually about 20mA) if set to HIGH

    pinMode(BAT_READ, OUTPUT);
    digitalWrite(BAT_READ, LOW); // This is pin P0_14 = 14 and by pullling low to GND it provices path to read on pin 32 (P0,31)
                                 // PIN_VBAT the voltage from divider on XIAO board

#endif

#if !MESHTASTIC_EXCLUDE_I2C
#if defined(I2C_SDA1) && defined(ARCH_RP2040)
    Wire1.setSDA(I2C_SDA1);
    Wire1.setSCL(I2C_SCL1);
    Wire1.begin();
#elif defined(I2C_SDA1) && !defined(ARCH_RP2040)
    Wire1.begin(I2C_SDA1, I2C_SCL1);
#endif

#if defined(I2C_SDA) && defined(ARCH_RP2040)
    Wire.setSDA(I2C_SDA);
    Wire.setSCL(I2C_SCL);
    Wire.begin();
#elif defined(I2C_SDA) && !defined(ARCH_RP2040)
    Wire.begin(I2C_SDA, I2C_SCL);
#elif defined(ARCH_PORTDUINO)
    if (settingsStrings[i2cdev] != "") {
        LOG_INFO("Using %s as I2C device.\n", settingsStrings[i2cdev].c_str());
        Wire.begin(settingsStrings[i2cdev].c_str());
    } else {
        LOG_INFO("No I2C device configured, skipping.\n");
    }
#elif HAS_WIRE
    Wire.begin();
#endif
#endif

#ifdef PIN_LCD_RESET
    // FIXME - move this someplace better, LCD is at address 0x3F
    pinMode(PIN_LCD_RESET, OUTPUT);
    digitalWrite(PIN_LCD_RESET, 0);
    delay(1);
    digitalWrite(PIN_LCD_RESET, 1);
    delay(1);
#endif

#ifdef AQ_SET_PIN
    // RAK-12039 set pin for Air quality sensor
    pinMode(AQ_SET_PIN, OUTPUT);
    digitalWrite(AQ_SET_PIN, HIGH);
#endif

#ifdef T_DECK
    // enable keyboard
    pinMode(KB_POWERON, OUTPUT);
    digitalWrite(KB_POWERON, HIGH);
    // There needs to be a delay after power on, give LILYGO-KEYBOARD some startup time
    // otherwise keyboard and touch screen will not work
    delay(800);
#endif

    // Currently only the tbeam has a PMU
    // PMU initialization needs to be placed before i2c scanning
    power = new Power();
    power->setStatusHandler(powerStatus);
    powerStatus->observe(&power->newStatus);
    power->setup(); // Must be after status handler is installed, so that handler gets notified of the initial configuration

#if !MESHTASTIC_EXCLUDE_I2C
    // We need to scan here to decide if we have a screen for nodeDB.init() and because power has been applied to
    // accessories
    auto i2cScanner = std::unique_ptr<ScanI2CTwoWire>(new ScanI2CTwoWire());
#if HAS_WIRE
    LOG_INFO("Scanning for i2c devices...\n");
#endif

#if defined(I2C_SDA1) && defined(ARCH_RP2040)
    Wire1.setSDA(I2C_SDA1);
    Wire1.setSCL(I2C_SCL1);
    Wire1.begin();
    i2cScanner->scanPort(ScanI2C::I2CPort::WIRE1);
#elif defined(I2C_SDA1) && !defined(ARCH_RP2040)
    Wire1.begin(I2C_SDA1, I2C_SCL1);
    i2cScanner->scanPort(ScanI2C::I2CPort::WIRE1);
#endif

#if defined(I2C_SDA) && defined(ARCH_RP2040)
    Wire.setSDA(I2C_SDA);
    Wire.setSCL(I2C_SCL);
    Wire.begin();
    i2cScanner->scanPort(ScanI2C::I2CPort::WIRE);
#elif defined(I2C_SDA) && !defined(ARCH_RP2040)
    Wire.begin(I2C_SDA, I2C_SCL);
    i2cScanner->scanPort(ScanI2C::I2CPort::WIRE);
#elif defined(ARCH_PORTDUINO)
    if (settingsStrings[i2cdev] != "") {
        LOG_INFO("Scanning for i2c devices...\n");
        i2cScanner->scanPort(ScanI2C::I2CPort::WIRE);
    }
#elif HAS_WIRE
    i2cScanner->scanPort(ScanI2C::I2CPort::WIRE);
#endif

    auto i2cCount = i2cScanner->countDevices();
    if (i2cCount == 0) {
        LOG_INFO("No I2C devices found\n");
    } else {
        LOG_INFO("%i I2C devices found\n", i2cCount);
    }

#ifdef ARCH_ESP32
    // Don't init display if we don't have one or we are waking headless due to a timer event
    if (wakeCause == ESP_SLEEP_WAKEUP_TIMER) {
        LOG_DEBUG("suppress screen wake because this is a headless timer wakeup");
        i2cScanner->setSuppressScreen();
    }
#endif

    auto screenInfo = i2cScanner->firstScreen();
    screen_found = screenInfo.type != ScanI2C::DeviceType::NONE ? screenInfo.address : ScanI2C::ADDRESS_NONE;

    if (screen_found.port != ScanI2C::I2CPort::NO_I2C) {
        switch (screenInfo.type) {
        case ScanI2C::DeviceType::SCREEN_SH1106:
            screen_model = meshtastic_Config_DisplayConfig_OledType::meshtastic_Config_DisplayConfig_OledType_OLED_SH1106;
            break;
        case ScanI2C::DeviceType::SCREEN_SSD1306:
            screen_model = meshtastic_Config_DisplayConfig_OledType::meshtastic_Config_DisplayConfig_OledType_OLED_SSD1306;
            break;
        case ScanI2C::DeviceType::SCREEN_ST7567:
        case ScanI2C::DeviceType::SCREEN_UNKNOWN:
        default:
            screen_model = meshtastic_Config_DisplayConfig_OledType::meshtastic_Config_DisplayConfig_OledType_OLED_AUTO;
        }
    }

#define UPDATE_FROM_SCANNER(FIND_FN)

    auto rtc_info = i2cScanner->firstRTC();
    rtc_found = rtc_info.type != ScanI2C::DeviceType::NONE ? rtc_info.address : rtc_found;

    auto kb_info = i2cScanner->firstKeyboard();

    if (kb_info.type != ScanI2C::DeviceType::NONE) {
        cardkb_found = kb_info.address;
        switch (kb_info.type) {
        case ScanI2C::DeviceType::RAK14004:
            kb_model = 0x02;
            break;
        case ScanI2C::DeviceType::CARDKB:
            kb_model = 0x00;
            break;
        case ScanI2C::DeviceType::TDECKKB:
            // assign an arbitrary value to distinguish from other models
            kb_model = 0x10;
            break;
        case ScanI2C::DeviceType::BBQ10KB:
            // assign an arbitrary value to distinguish from other models
            kb_model = 0x11;
            break;
        default:
            // use this as default since it's also just zero
            LOG_WARN("kb_info.type is unknown(0x%02x), setting kb_model=0x00\n", kb_info.type);
            kb_model = 0x00;
        }
    }

    pmu_found = i2cScanner->exists(ScanI2C::DeviceType::PMU_AXP192_AXP2101);

/*
 * There are a bunch of sensors that have no further logic than to be found and stuffed into the
 * nodeTelemetrySensorsMap singleton. This wraps that logic in a temporary scope to declare the temporary field
 * "found".
 */

// Only one supported RGB LED currently
#ifdef HAS_NCP5623
    rgb_found = i2cScanner->find(ScanI2C::DeviceType::NCP5623);
#endif

#if !defined(ARCH_PORTDUINO) && !defined(ARCH_STM32WL)
    auto acc_info = i2cScanner->firstAccelerometer();
    accelerometer_found = acc_info.type != ScanI2C::DeviceType::NONE ? acc_info.address : accelerometer_found;
    LOG_DEBUG("acc_info = %i\n", acc_info.type);
#endif

#define STRING(S) #S

#define SCANNER_TO_SENSORS_MAP(SCANNER_T, PB_T)                                                                                  \
    {                                                                                                                            \
        auto found = i2cScanner->find(SCANNER_T);                                                                                \
        if (found.type != ScanI2C::DeviceType::NONE) {                                                                           \
            nodeTelemetrySensorsMap[PB_T].first = found.address.address;                                                         \
            nodeTelemetrySensorsMap[PB_T].second = i2cScanner->fetchI2CBus(found.address);                                       \
            LOG_DEBUG("found i2c sensor %s\n", STRING(PB_T));                                                                    \
        }                                                                                                                        \
    }

    SCANNER_TO_SENSORS_MAP(ScanI2C::DeviceType::BME_680, meshtastic_TelemetrySensorType_BME680)
    SCANNER_TO_SENSORS_MAP(ScanI2C::DeviceType::BME_280, meshtastic_TelemetrySensorType_BME280)
    SCANNER_TO_SENSORS_MAP(ScanI2C::DeviceType::BMP_280, meshtastic_TelemetrySensorType_BMP280)
    SCANNER_TO_SENSORS_MAP(ScanI2C::DeviceType::BMP_085, meshtastic_TelemetrySensorType_BMP085)
    SCANNER_TO_SENSORS_MAP(ScanI2C::DeviceType::INA260, meshtastic_TelemetrySensorType_INA260)
    SCANNER_TO_SENSORS_MAP(ScanI2C::DeviceType::INA219, meshtastic_TelemetrySensorType_INA219)
    SCANNER_TO_SENSORS_MAP(ScanI2C::DeviceType::INA3221, meshtastic_TelemetrySensorType_INA3221)
    SCANNER_TO_SENSORS_MAP(ScanI2C::DeviceType::MCP9808, meshtastic_TelemetrySensorType_MCP9808)
    SCANNER_TO_SENSORS_MAP(ScanI2C::DeviceType::MCP9808, meshtastic_TelemetrySensorType_MCP9808)
    SCANNER_TO_SENSORS_MAP(ScanI2C::DeviceType::SHT31, meshtastic_TelemetrySensorType_SHT31)
    SCANNER_TO_SENSORS_MAP(ScanI2C::DeviceType::SHTC3, meshtastic_TelemetrySensorType_SHTC3)
    SCANNER_TO_SENSORS_MAP(ScanI2C::DeviceType::LPS22HB, meshtastic_TelemetrySensorType_LPS22)
    SCANNER_TO_SENSORS_MAP(ScanI2C::DeviceType::QMC6310, meshtastic_TelemetrySensorType_QMC6310)
    SCANNER_TO_SENSORS_MAP(ScanI2C::DeviceType::QMI8658, meshtastic_TelemetrySensorType_QMI8658)
    SCANNER_TO_SENSORS_MAP(ScanI2C::DeviceType::QMC5883L, meshtastic_TelemetrySensorType_QMC5883L)
    SCANNER_TO_SENSORS_MAP(ScanI2C::DeviceType::PMSA0031, meshtastic_TelemetrySensorType_PMSA003I)
    SCANNER_TO_SENSORS_MAP(ScanI2C::DeviceType::RCWL9620, meshtastic_TelemetrySensorType_RCWL9620)
    SCANNER_TO_SENSORS_MAP(ScanI2C::DeviceType::VEML7700, meshtastic_TelemetrySensorType_VEML7700)
    SCANNER_TO_SENSORS_MAP(ScanI2C::DeviceType::TSL2591, meshtastic_TelemetrySensorType_TSL25911FN)
    SCANNER_TO_SENSORS_MAP(ScanI2C::DeviceType::OPT3001, meshtastic_TelemetrySensorType_OPT3001)
    SCANNER_TO_SENSORS_MAP(ScanI2C::DeviceType::MLX90632, meshtastic_TelemetrySensorType_MLX90632)
    SCANNER_TO_SENSORS_MAP(ScanI2C::DeviceType::SHT4X, meshtastic_TelemetrySensorType_SHT4X)
    SCANNER_TO_SENSORS_MAP(ScanI2C::DeviceType::AHT10, meshtastic_TelemetrySensorType_AHT10)
    SCANNER_TO_SENSORS_MAP(ScanI2C::DeviceType::DFROBOT_LARK, meshtastic_TelemetrySensorType_DFROBOT_LARK)

    i2cScanner.reset();
#endif

#ifdef HAS_SDCARD
    setupSDCard();
#endif

    // LED init

#ifdef LED_PIN
    pinMode(LED_PIN, OUTPUT);
    digitalWrite(LED_PIN, 1 ^ LED_INVERTED); // turn on for now
#endif

    // Hello
    printInfo();

#ifdef ARCH_ESP32
    esp32Setup();
#endif

#ifdef ARCH_NRF52
    nrf52Setup();
#endif

#ifdef ARCH_RP2040
    rp2040Setup();
#endif

    // We do this as early as possible because this loads preferences from flash
    // but we need to do this after main cpu init (esp32setup), because we need the random seed set
    nodeDB = new NodeDB;

    // If we're taking on the repeater role, use flood router and turn off 3V3_S rail because peripherals are not needed
    if (config.device.role == meshtastic_Config_DeviceConfig_Role_REPEATER) {
        router = new FloodingRouter();
#ifdef PIN_3V3_EN
        digitalWrite(PIN_3V3_EN, LOW);
#endif
    } else
        router = new ReliableRouter();

#if HAS_BUTTON || defined(ARCH_PORTDUINO)
    // Buttons. Moved here cause we need NodeDB to be initialized
    buttonThread = new ButtonThread();
#endif

    playStartMelody();

    // fixed screen override?
    if (config.display.oled != meshtastic_Config_DisplayConfig_OledType_OLED_AUTO)
        screen_model = config.display.oled;

#if defined(USE_SH1107)
    screen_model = meshtastic_Config_DisplayConfig_OledType_OLED_SH1107; // set dimension of 128x128
    display_geometry = GEOMETRY_128_128;
#endif

#if defined(USE_SH1107_128_64)
    screen_model = meshtastic_Config_DisplayConfig_OledType_OLED_SH1107; // keep dimension of 128x64
#endif
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
void loop()
{
    runASAP = false;

    // axpDebugOutput.loop();

    // heap_caps_check_integrity_all(true); // FIXME - disable this expensive check

#ifdef ARCH_ESP32
    esp32Loop();
#endif
#ifdef ARCH_NRF52
    nrf52Loop();
#endif
    powerCommandsCheck();

    // For debugging
    // if (rIf) ((RadioLibInterface *)rIf)->isActivelyReceiving();

#ifdef DEBUG_STACK
    static uint32_t lastPrint = 0;
    if (millis() - lastPrint > 10 * 1000L) {
        lastPrint = millis();
        meshtastic::printThreadInfo("main");
    }
#endif

    // TODO: This should go into a thread handled by FreeRTOS.
    // handleWebResponse();

    service.loop();

    long delayMsec = mainController.runOrDelay();

    /* if (mainController.nextThread && delayMsec)
        LOG_DEBUG("Next %s in %ld\n", mainController.nextThread->ThreadName.c_str(),
                  mainController.nextThread->tillRun(millis())); */

    // We want to sleep as long as possible here - because it saves power
    if (!runASAP && loopCanSleep()) {
        // if(delayMsec > 100) LOG_DEBUG("sleeping %ld\n", delayMsec);
        mainDelay.delay(delayMsec);
    }
    // if (didWake) LOG_DEBUG("wake!\n");
}

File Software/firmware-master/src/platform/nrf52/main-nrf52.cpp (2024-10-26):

#include "configuration.h"
#include <Adafruit_TinyUSB.h>
#include <Adafruit_nRFCrypto.h>
#include <SPI.h>
#include <Wire.h>
#include <assert.h>
#include <ble_gap.h>
#include <memory.h>
#include <stdio.h>
// #include <Adafruit_USBD_Device.h>
#include "NodeDB.h"
#include "error.h"
#include "main.h"

#ifdef BQ25703A_ADDR
#include "BQ25713.h"
#endif

static inline void debugger_break(void)
{
    __asm volatile("bkpt #0x01\n\t"
                   "mov pc, lr\n\t");
}

bool loopCanSleep()
{
    // turn off sleep only while connected via USB
    // return true;
    return !Serial; // the bool operator on the nrf52 serial class returns true if connected to a PC currently
    // return !(TinyUSBDevice.mounted() && !TinyUSBDevice.suspended());
}

// handle standard gcc assert failures
void __attribute__((noreturn)) __assert_func(const char *file, int line, const char *func, const char *failedexpr)
{
    LOG_ERROR("assert failed %s: %d, %s, test=%s\n", file, line, func, failedexpr);
    // debugger_break(); FIXME doesn't work, possibly not for segger
    // Reboot cpu
    NVIC_SystemReset();
}

void getMacAddr(uint8_t *dmac)
{
    const uint8_t *src = (const uint8_t *)NRF_FICR->DEVICEADDR;
    dmac[5] = src[0];
    dmac[4] = src[1];
    dmac[3] = src[2];
    dmac[2] = src[3];
    dmac[1] = src[4];
    dmac[0] = src[5] | 0xc0; // MSB high two bits get set elsewhere in the bluetooth stack
}

static void initBrownout()
{
    auto vccthresh = POWER_POFCON_THRESHOLD_V24;

    auto err_code = sd_power_pof_enable(POWER_POFCON_POF_Enabled);
    assert(err_code == NRF_SUCCESS);

    err_code = sd_power_pof_threshold_set(vccthresh);
    assert(err_code == NRF_SUCCESS);

    // We don't bother with setting up brownout if soft device is disabled - because during production we always use softdevice
}

// This is a public global so that the debugger can set it to false automatically from our gdbinit
bool useSoftDevice = true; // Set to false for easier debugging

#if !MESHTASTIC_EXCLUDE_BLUETOOTH
void setBluetoothEnable(bool enable)
{
    // For debugging use: don't use bluetooth
    if (!useSoftDevice)
    {
        if (enable)
            LOG_INFO("DISABLING NRF52 BLUETOOTH WHILE DEBUGGING\n");
        return;
    }

    // If user disabled bluetooth: init then disable advertising & reduce power
    // Workaround. Avoid issue where device hangs several days after boot..
    // Allegedly, no significant increase in power consumption
    if (!config.bluetooth.enabled)
    {
        static bool initialized = false;
        if (!initialized)
        {
            nrf52Bluetooth = new NRF52Bluetooth();
            nrf52Bluetooth->startDisabled();
            initBrownout();
            initialized = true;
        }
        return;
    }

    if (enable)
    {
        // If not yet set-up
        if (!nrf52Bluetooth)
        {
            LOG_DEBUG("Initializing NRF52 Bluetooth\n");
            nrf52Bluetooth = new NRF52Bluetooth();
            nrf52Bluetooth->setup();

            // We delay brownout init until after BLE because BLE starts soft device
            initBrownout();
        }
        // Already setup, apparently
        else
            nrf52Bluetooth->resumeAdvertising();
    }
    // Disable (if previously set-up)
    else if (nrf52Bluetooth)
        nrf52Bluetooth->shutdown();
}
#else
#warning NRF52 "Bluetooth disable" workaround does not apply to builds with MESHTASTIC_EXCLUDE_BLUETOOTH
void setBluetoothEnable(bool enable) {}
#endif
/**
 * Override printf to use the SEGGER output library (note - this does not effect the printf method on the debug console)
 */
int printf(const char *fmt, ...)
{
    va_list args;
    va_start(args, fmt);
    auto res = SEGGER_RTT_vprintf(0, fmt, &args);
    va_end(args);
    return res;
}

void checkSDEvents()
{
    if (useSoftDevice)
    {
        uint32_t evt;
        while (NRF_SUCCESS == sd_evt_get(&evt))
        {
            switch (evt)
            {
            case NRF_EVT_POWER_FAILURE_WARNING:
                RECORD_CRITICALERROR(meshtastic_CriticalErrorCode_BROWNOUT);
                break;

            default:
                LOG_DEBUG("Unexpected SDevt %d\n", evt);
                break;
            }
        }
    }
    else
    {
        if (NRF_POWER->EVENTS_POFWARN)
            RECORD_CRITICALERROR(meshtastic_CriticalErrorCode_BROWNOUT);
    }
}

void nrf52Loop()
{
    checkSDEvents();
}

#ifdef USE_SEMIHOSTING
#include <SemihostingStream.h>

/**
 * Note: this variable is in BSS and therfore false by default.  But the gdbinit
 * file will be installing a temporary breakpoint that changes wantSemihost to true.
 */
bool wantSemihost;

/**
 * Turn on semihosting if the ICE debugger wants it.
 */
void nrf52InitSemiHosting()
{
    if (wantSemihost)
    {
        static SemihostingStream semiStream;
        // We must dynamically alloc because the constructor does semihost operations which
        // would crash any load not talking to a debugger
        semiStream.open();
        semiStream.println("Semihosting starts!");
        // Redirect our serial output to instead go via the ICE port
        console->setDestination(&semiStream);
    }
}
#endif

void nrf52Setup()
{
    uint32_t why = NRF_POWER->RESETREAS;
    // per
    // https://infocenter.nordicsemi.com/index.jsp?topic=%2Fcom.nordic.infocenter.nrf52832.ps.v1.1%2Fpower.html
    LOG_DEBUG("Reset reason: 0x%x\n", why);

#ifdef USE_SEMIHOSTING
    nrf52InitSemiHosting();
#endif

    // Per
    // https://devzone.nordicsemi.com/nordic/nordic-blog/b/blog/posts/monitor-mode-debugging-with-j-link-and-gdbeclipse
    // This is the recommended setting for Monitor Mode Debugging
    NVIC_SetPriority(DebugMonitor_IRQn, 6UL);

#ifdef BQ25703A_ADDR
    auto *bq = new BQ25713();
    if (!bq->setup())
        LOG_ERROR("ERROR! Charge controller init failed\n");
#endif

    // Init random seed
    union seedParts
    {
        uint32_t seed32;
        uint8_t seed8[4];
    } seed;
    nRFCrypto.begin();
    nRFCrypto.Random.generate(seed.seed8, sizeof(seed.seed8));
    LOG_DEBUG("Setting random seed %u\n", seed.seed32);
    randomSeed(seed.seed32);
    nRFCrypto.end();
}

void cpuDeepSleep(uint32_t msecToWake)
{
    // FIXME, configure RTC or button press to wake us
    // FIXME, power down SPI, I2C, RAMs
#if HAS_WIRE
    Wire.end();
#endif
    SPI.end();
    SPI1.end();
    // This may cause crashes as debug messages continue to flow.
    Serial.end();
    Serial1.end();
    Serial2.end();
#ifdef PIN_SERIAL_RX1
    Serial1.end();
#endif
    setBluetoothEnable(false);
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

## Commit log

2024-10-01 提交文件
    [.isort.cfg, configuration.h, meshtastic_V1.0.kicad_pcb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]
2024-10-11 Create Meshtastic devices.pdf
2024-10-15 Version update
    [UL840+1262.kicad_pcb, UL840+1262.kicad_sch]
2024-10-15 update firmware
    Resolve the screen flickering bug
    [meshtastic_V2.0.kicad_pcb, meshtastic_V2.0.kicad_sch]
2024-10-26 Fixed compilation errors
    bmaSensor.setReampAxes(bmaSensor.REMAP_BOTTOM_LAYER_BOTTOM_LEFT_CORNER); Change to bmaSensor.MAPsetRemapAxes(bmaSensor.REMAP_BOTTOM_LAYER_BOTTOM_LEFT_CORNER)
    [AccelerometerThread.h, Default.h, GPS.cpp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]
